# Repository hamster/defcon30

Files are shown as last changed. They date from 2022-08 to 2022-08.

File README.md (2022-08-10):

# defcon 30 SAOs

Hello!  I'm [@hamster](https://twitter.com/hamster) and I was honored this year to be able to make a couple of SAOs for defcon.  I tried to make these simple and fun, and I hope you enjoy them.

The first one is the [SAO Modem 1.69bis](modem), which is a throwback to the days of the external Courier modem screaming away at the internet.  It does not actually communicate with the internet, but it sure is blinky.

modem

The second one is [SAO Jack](jack), a simple learn to solder kit with the spirit of defcon in the artwork.

jack

I hope you enjoy, and let [me](https://twitter.com/hamster) know what you think!

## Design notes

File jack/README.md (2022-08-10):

# Jack SAO

jack

Jack is a simple SAO soldering kit.  Consisting of 4 LEDs in two colors, two resistors, and a connector, it's an easy way to learn how to solder.

To start, dump your kit out on the table and make sure you have all the parts pictured.  You'll need a soldering iron, solder, and a pair of wire cutters.

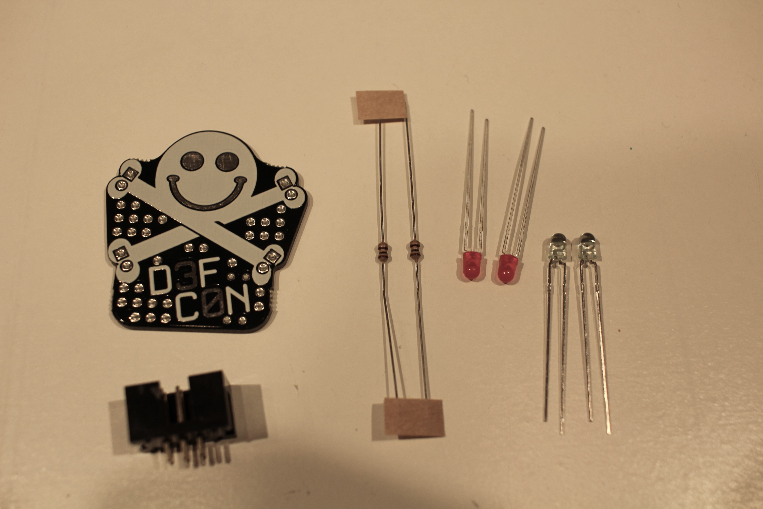
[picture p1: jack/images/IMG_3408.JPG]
parts


Locate the LEDs. Note that typically the LED is cast with a flat spot to indicate the cathode (or negative) terminal.  However, these small LEDS instead have the shorter leg as the cathode.

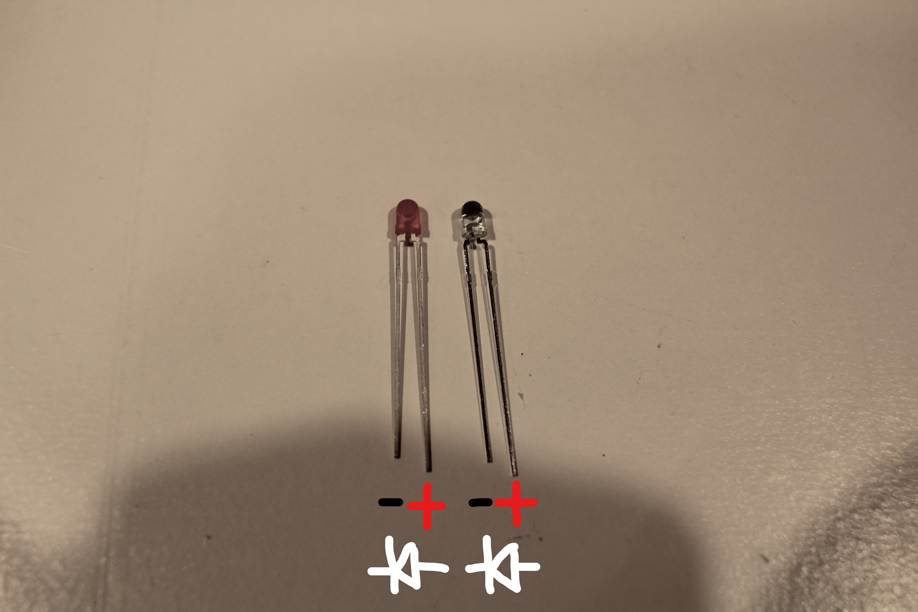
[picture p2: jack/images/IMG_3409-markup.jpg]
cathode


Look at the back of the PCB.  Note the diagram for the LEDS - the short legs of the LEDs will all go towards the top of the PCB.  This is also the square holes on the board.

It doesn't matter which color you put where.  Get crazy with it.  You can even leave the legs a little long and bend the LEDs to point out.  Whatever you want to do.

Insert the LEDs and flip over the PCB.  Make sure the short legs are going through the square holes.  Solder the legs into place.

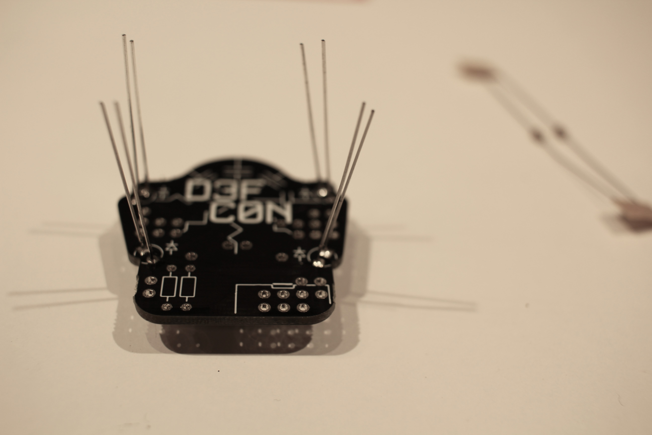
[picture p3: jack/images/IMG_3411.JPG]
legs


Now that the LEDs are in place, you can clip the legs off with your wire cutters.

Locate the two resistors.  Bend their legs down and insert them from the back into the holes above and below the two rectangles on the lower left as shown.

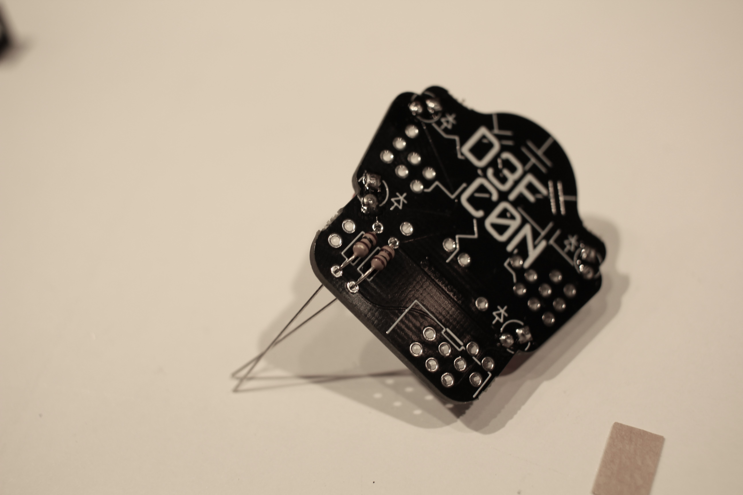
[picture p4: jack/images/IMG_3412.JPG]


Now flip the board over and push the resistors flat.  It helps here to bend the legs out so they can't slip while you are soldering.  Solder the legs down, and clip off the excess legs.

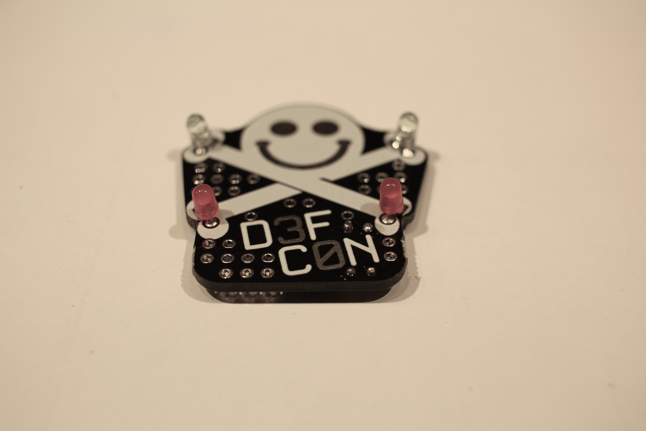
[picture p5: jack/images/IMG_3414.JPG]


Finally, we need to install the SAO connector.  Locate the connector, and note on the back that the notch or tab needs to go 'up'.

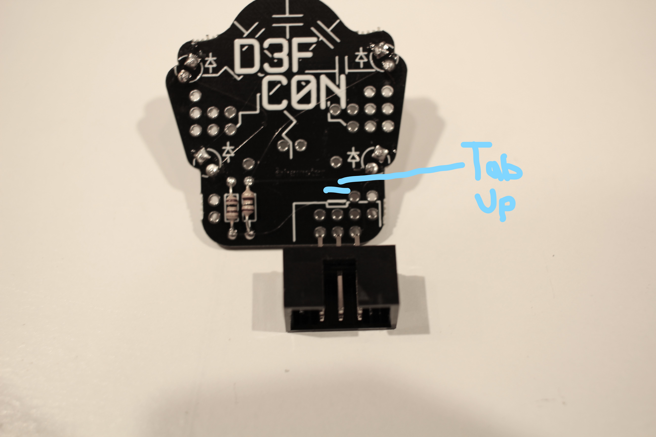
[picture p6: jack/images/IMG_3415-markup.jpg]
SAO


Flip the board over, and solder the connector on.  I like to solder one pin, and then lift the board and pinch the connector while re-applying heat so that the connector is mounted flat, before finishing the solder of the rest of the pins.

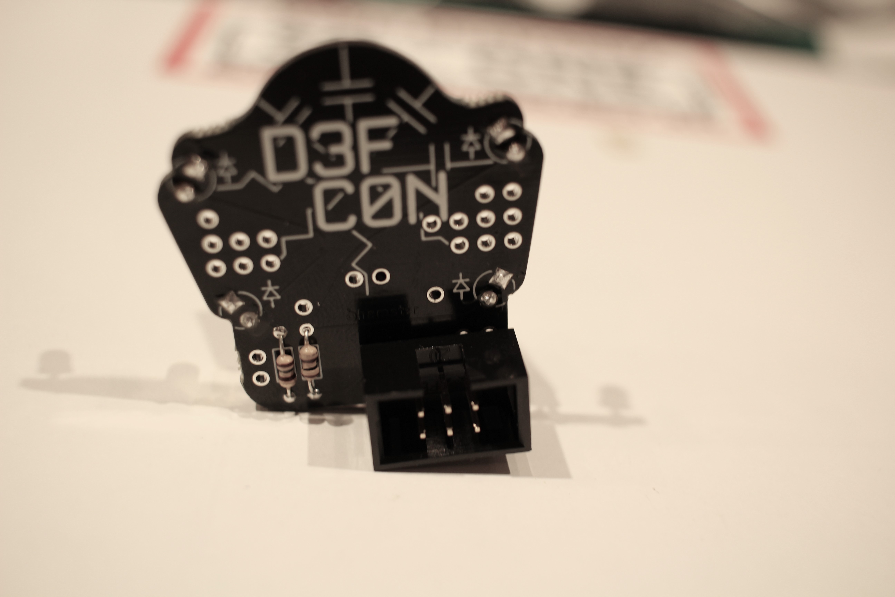
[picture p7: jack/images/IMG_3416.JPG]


You're all done!  Enjoy your SAO and let [me](https://twitter.com/hamster) know what you think!

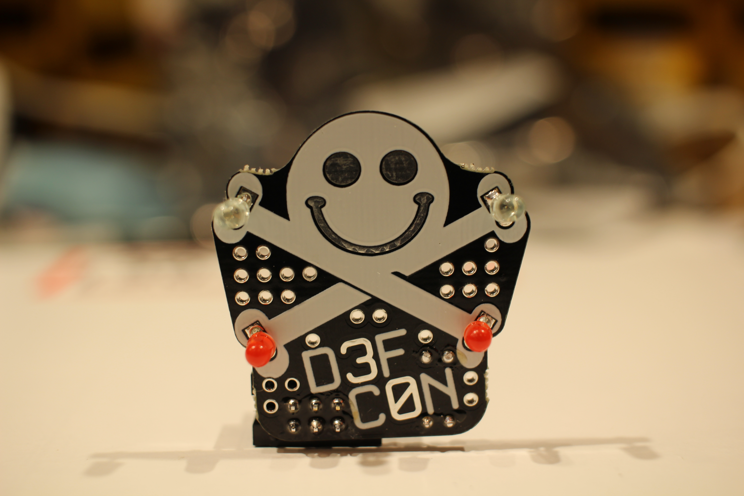
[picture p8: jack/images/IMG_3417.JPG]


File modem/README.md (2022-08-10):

# SAO Modem 1.69bis

SAO

This SAO is designed to add some blinky lights to your badge, calling back to the days of an external Courier modem screaming away on the internet.

There are 6 lights:

- AA - Power, lights when 3.3v is present
- OH - Flashes on I2C SCL activity
- SD - Flashes on I2C SDA activity
- RTS - Flashes on GPIO1 activity
- CTS - Flashes on GPIO2 activity
- SYN - Connected to a free pad on the back, you choose what it does

The I2C inputs were selected to minimize load on the I2C bus, but this SAO might cause issues with badges with high speed I2C.  In that case, you can swap R7 and R8 for higher value resistors.

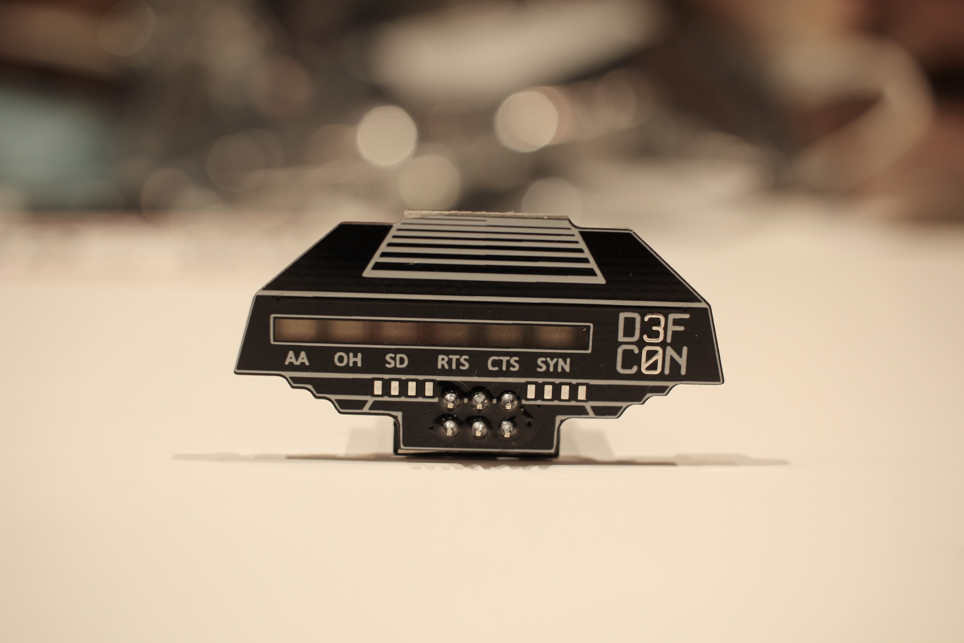
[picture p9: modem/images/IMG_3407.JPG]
SAO


You will need to solder on the SAO connector.  Note that the notch or tab goes towards the top.  See photo for reference.  I like to insert the connector, solder one pin, then pinch the connector to the board with my fingers and re-heat this connection so that the connector snaps flat to the board before I solder on the rest of the pins.

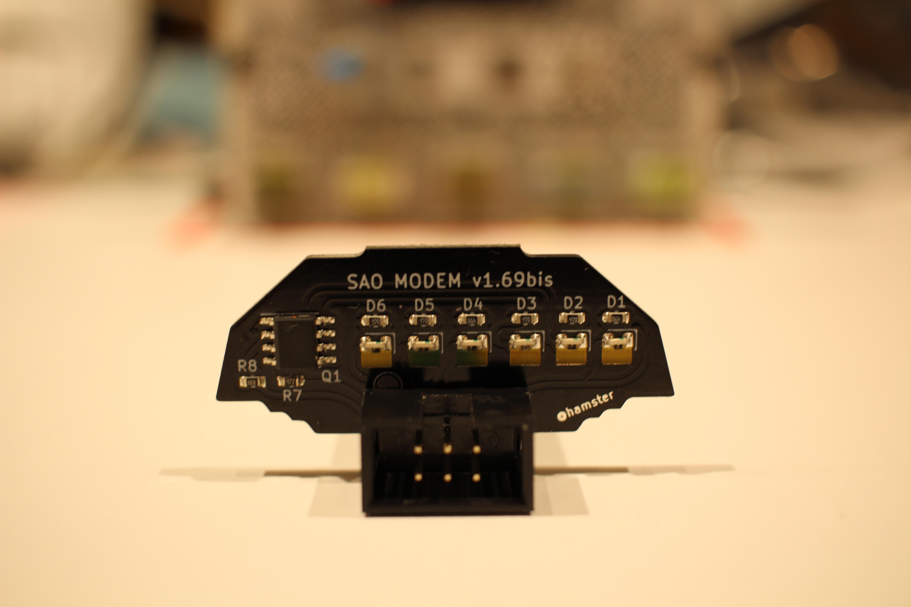
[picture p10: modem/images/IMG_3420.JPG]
connector


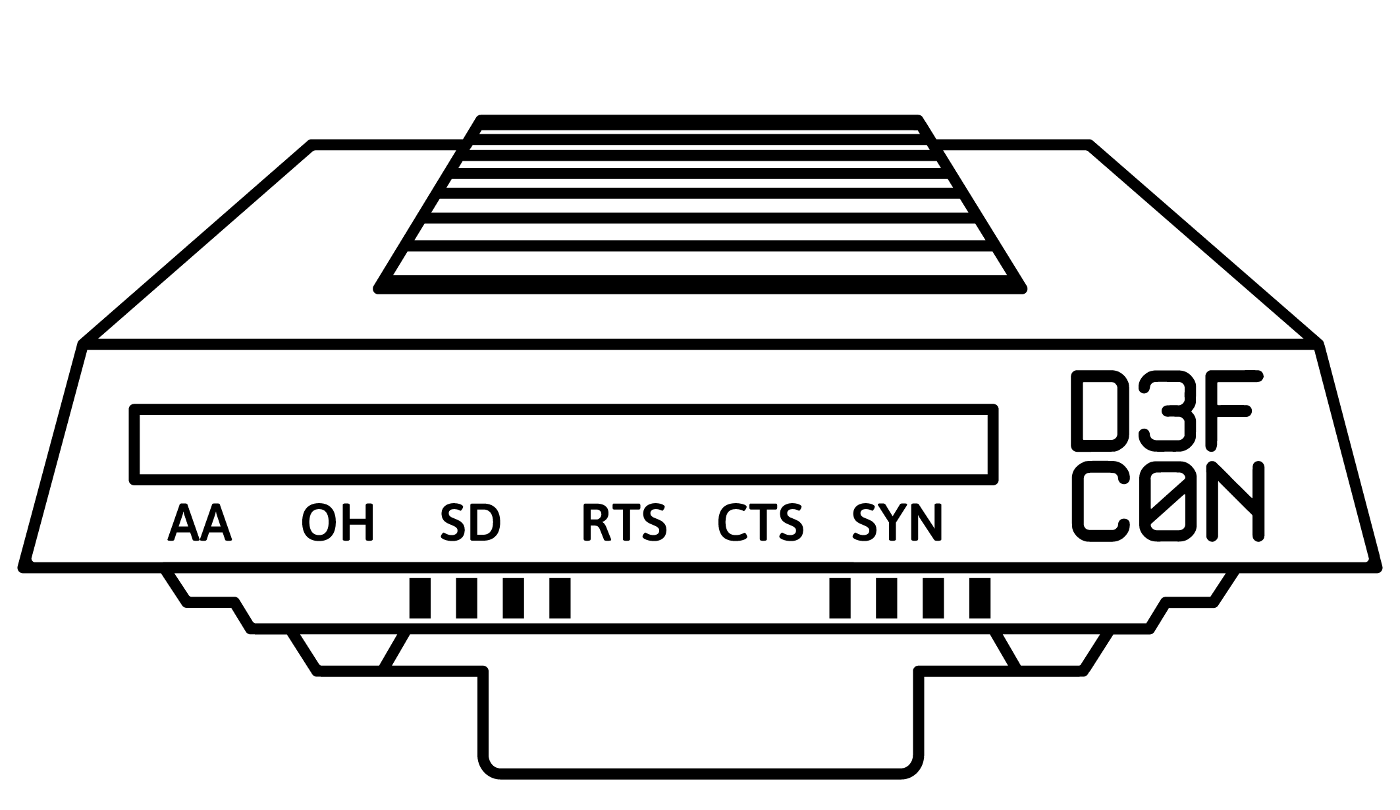
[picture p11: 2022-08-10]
modem/images/modem_Modem.png

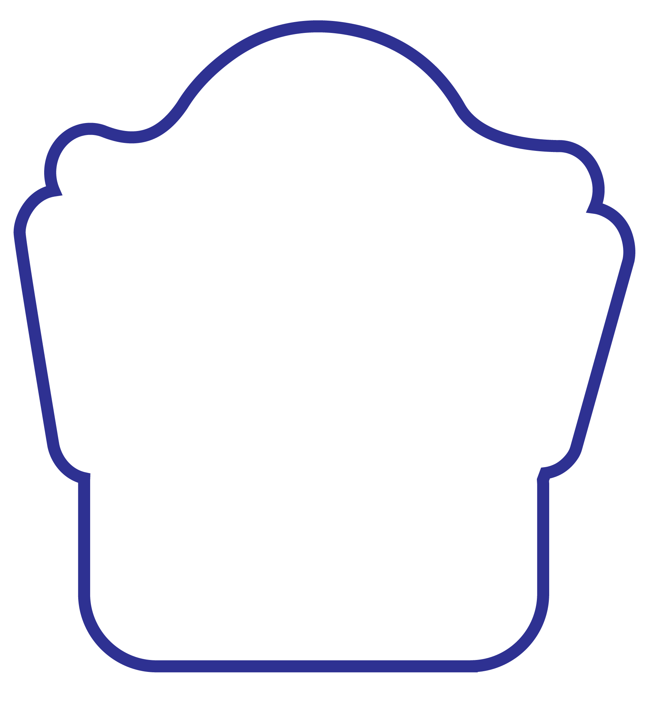
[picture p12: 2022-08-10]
jack/images/jack_Outline.png

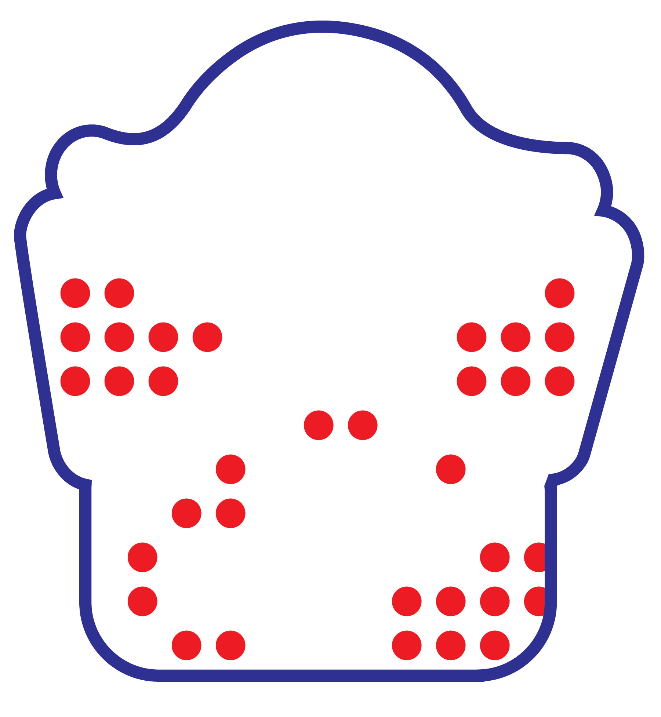
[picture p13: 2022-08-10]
jack/images/jack_Back.png

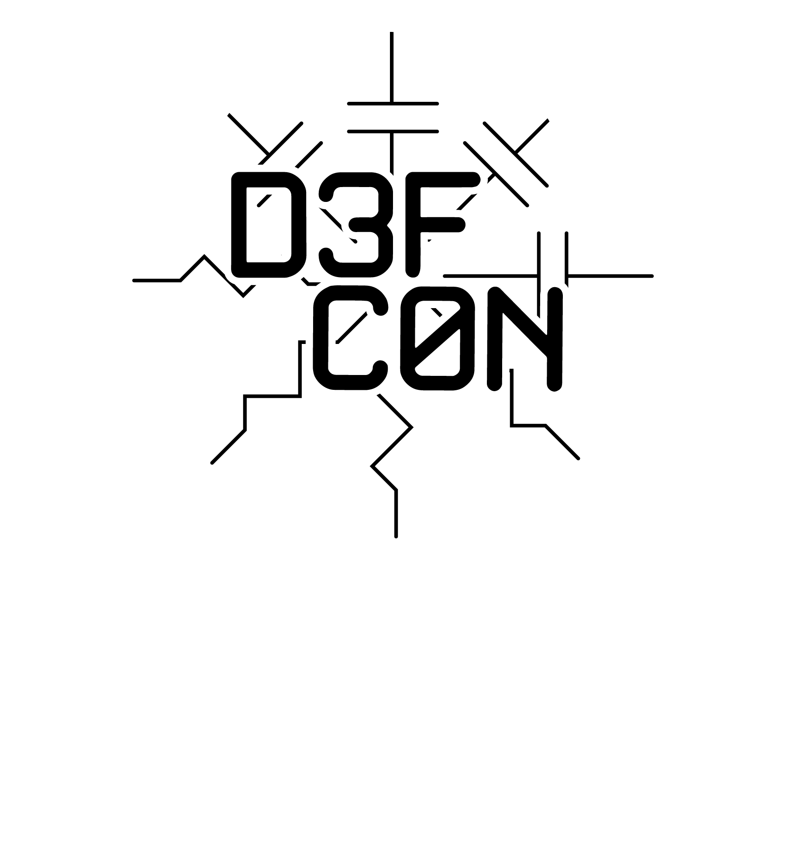
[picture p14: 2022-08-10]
jack/images/jack-06.png

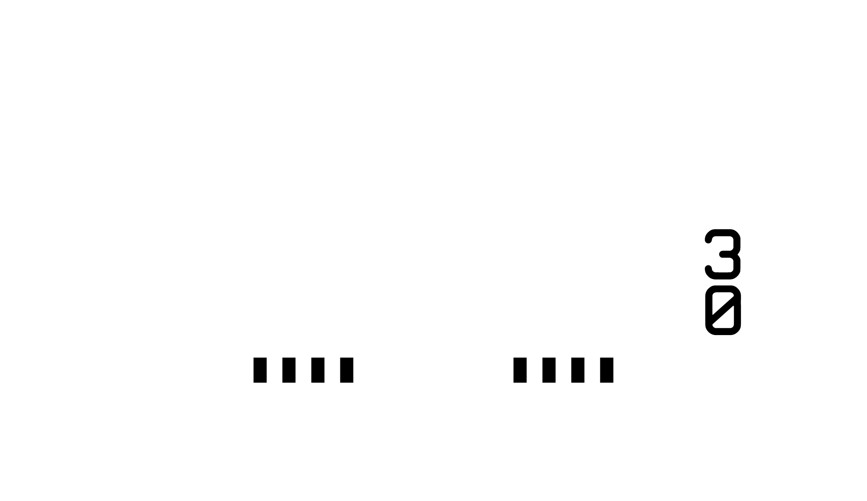
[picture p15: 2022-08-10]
modem/images/modem_Copper.png

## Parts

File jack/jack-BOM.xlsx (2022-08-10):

RefDes | Description | Part | Supplier Link | Qty/Badge
D1,D3 | Green T1 LED | HLMP1540 | https://www.digikey.com/en/products/detail/everlight-electronics-co-ltd/HLMP1540/2675537 | 2
D2,D4 | Red T1 LED | LTL-4211N | https://www.digikey.com/en/products/detail/liteon/LTL-4211N/3198521 | 2
R1,R2 | 100 ohm 1/8W resistor | CF18JT100R | https://www.digikey.com/en/products/detail/stackpole-electronics-inc/CF18JT100R/1741562 | 2
X1 | SAO connector, shrouded | 61200621621 | https://www.mouser.com/ProductDetail/710-61200621621 | 1

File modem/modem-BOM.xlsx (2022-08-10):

RefDes | Description | Part | Supplier Link | Supplier Part | Qty/Badge
D1-6 | Red LED RA 0805 | LTST-S220KRKT | https://www.digikey.com/en/products/detail/LTST-S220KRKT/160-1469-1-ND/386876 | 160-1469-2-ND | 6
R1-6 | 47R 0603 | RMCF0603FT47R0 | https://www.digikey.com/en/products/detail/stackpole-electronics-inc/RMCF0603FT47R0/1761141 | RMCF0603FT47R0TR-ND | 6
R7 | 4.7k 0603 | RMCF0603JT4K70 | https://www.digikey.com/en/products/detail/stackpole-electronics-inc/RMCF0603JT4K70/1757976 | RMCF0603JT4K70TR-ND | 1
R8 | 10k 0603 | RMCF0603JT10K0 | https://www.digikey.com/en/products/detail/stackpole-electronics-inc/RMCF0603JT10K0/1758104 | RMCF0603JT10K0TR-ND | 1
Q1 | Dual P-chan mosfet SOIC-8 | DMP3085LSD-13 | https://www.digikey.com/en/products/detail/diodes-incorporated/DMP3085LSD-13/4251562 | DMP3085LSD-13DITR-ND | 1
X1 | SAO connector, shrouded | 61200621621 | https://www.digikey.com/en/products/detail/61200621621/732-5394-ND/4846913 | 732-5394-ND | 1

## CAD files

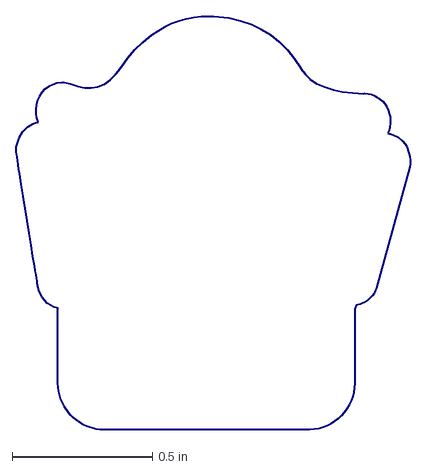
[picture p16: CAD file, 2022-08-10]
jack/images/jack-outline.dxf
1.40 x 1.47 in

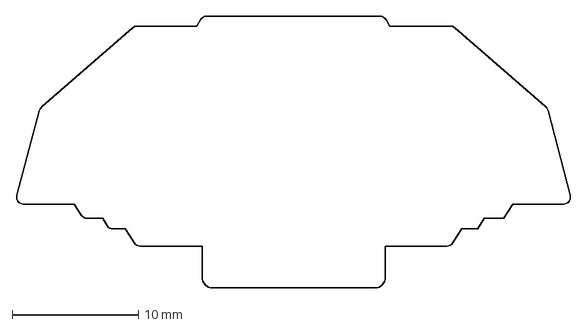
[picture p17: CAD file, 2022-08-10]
modem/images/modem.dxf
43.9 x 21.5 mm

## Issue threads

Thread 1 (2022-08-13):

Screen doesn’t turn on on DC30 badge after installing Modem SAO

abjugard, 2022-08-13:
The screen doesn’t turn on on DC30 badge after installing the Modem SAO. What is the solution that can be applied at the con?

hamster, 2022-08-13:
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
The SAO loads the i2c bus too much. It's not being used for the SAO other than to flash activity. You can replace R7 and R8 with higher value resistors or cut the i2c lines as indicated on the badge (see photo).

hamster, 2022-08-13:
R7 and R8 are on the modem SAO.

Closed 2022-08-13.

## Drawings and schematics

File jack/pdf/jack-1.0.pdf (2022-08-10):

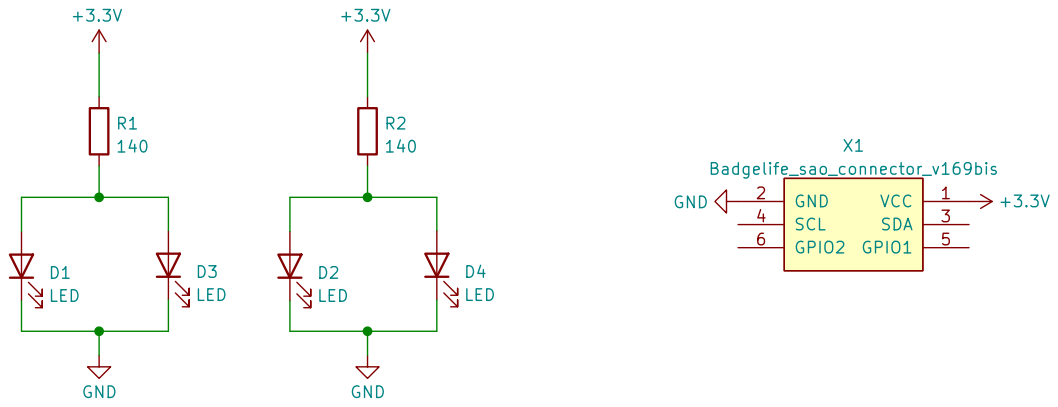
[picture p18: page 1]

github.com/hamster/defcon30 GND

File: jack.kicad_sch Sheet: / @hamster

Id: 1/1 Title: SAO Jack

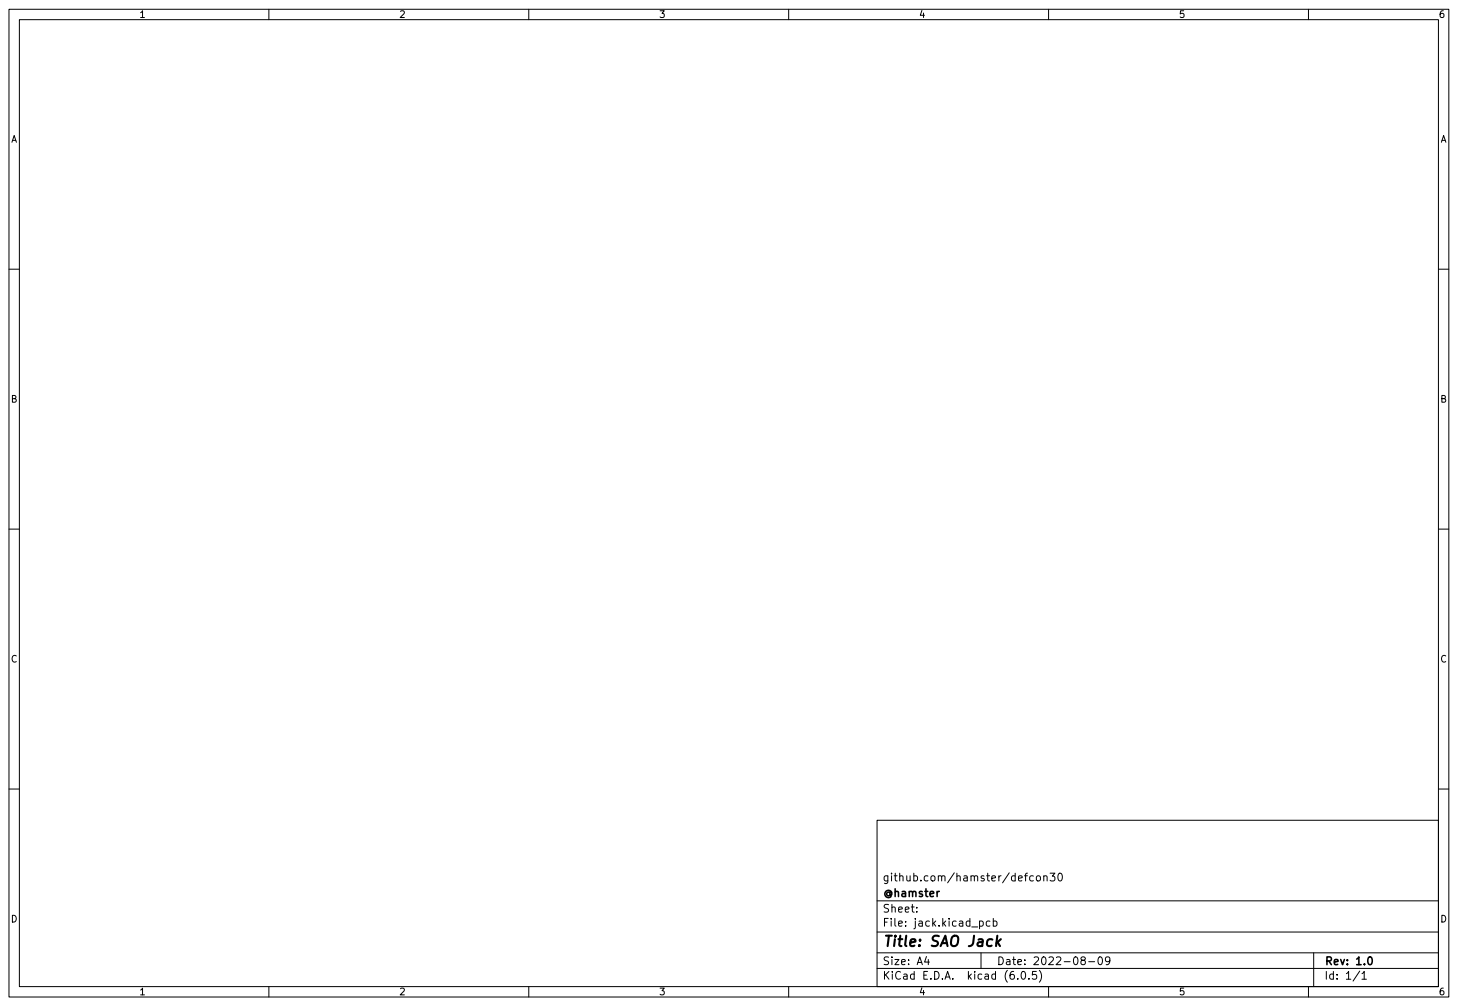
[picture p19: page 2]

github.com/hamster/defcon30
File: jack.kicad_pcb Sheet: @hamster

Id: 1/1 Title: SAO Jack

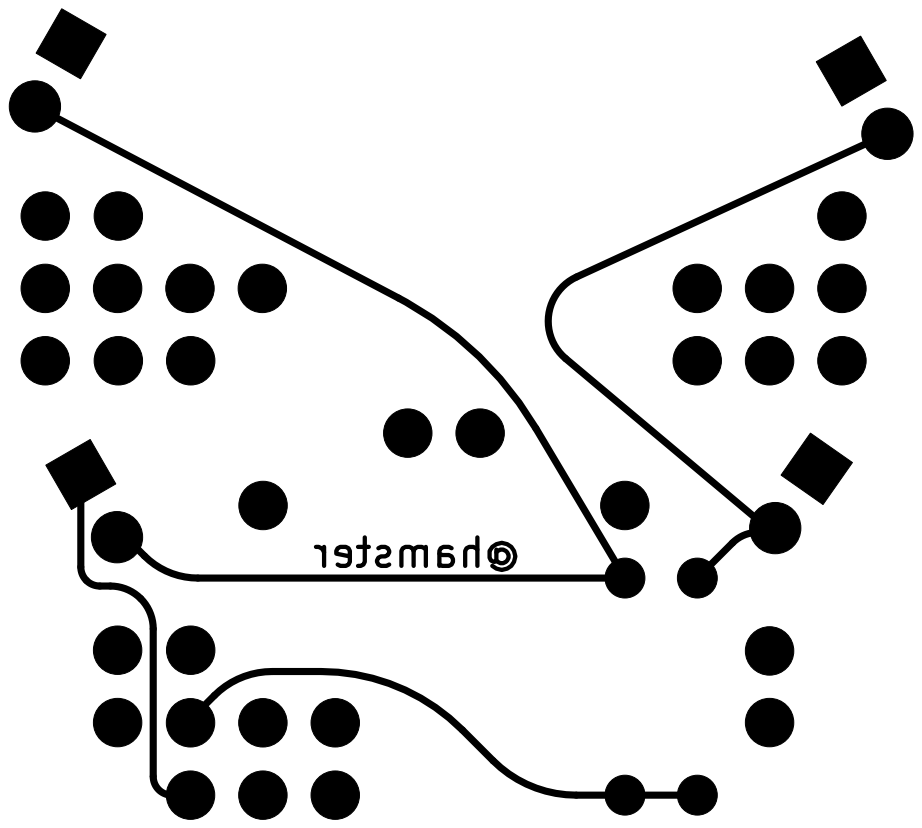
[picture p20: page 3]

github.com/hamster/defcon30 @hamster

File: jack.kicad_pcb Sheet: @hamster

Id: 1/1 Title: SAO Jack

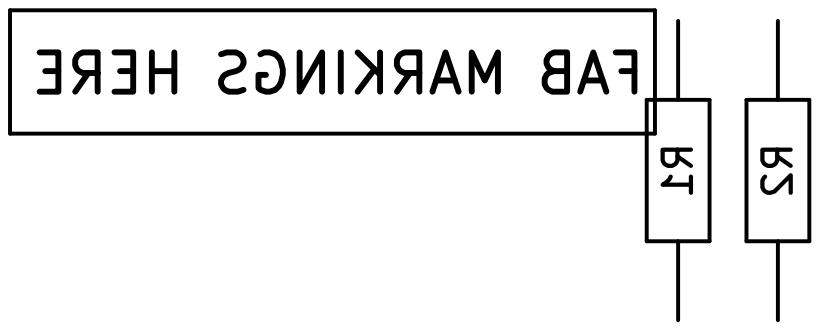
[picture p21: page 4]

github.com/hamster/defcon30
File: jack.kicad_pcb Sheet: @hamster

Id: 1/1 Title: SAO Jack

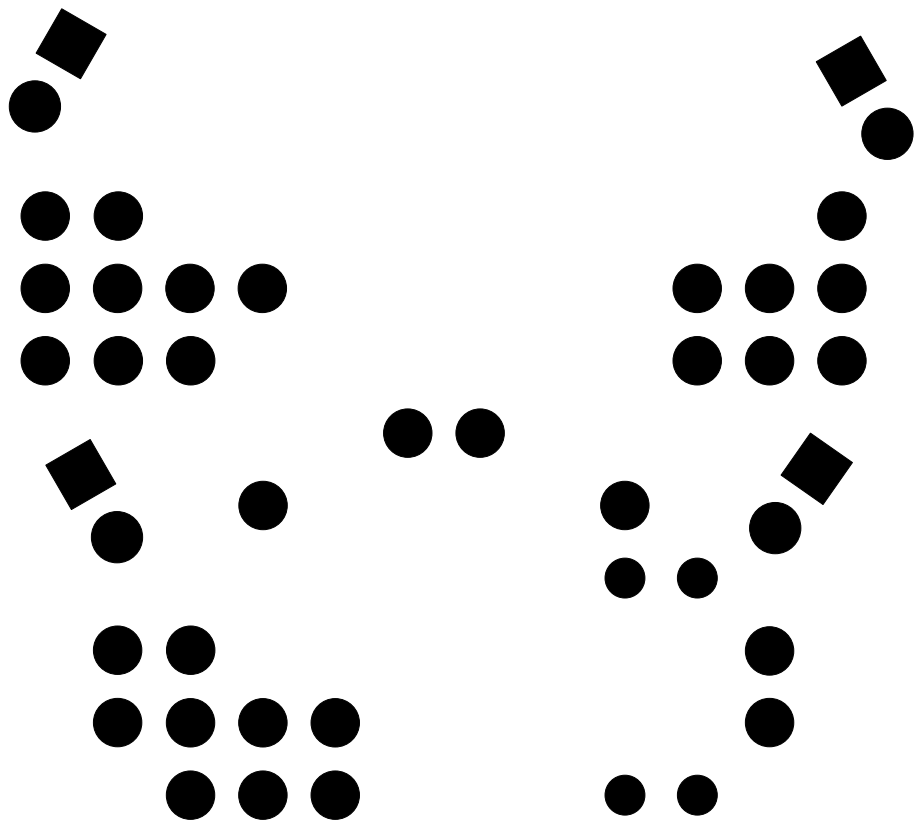
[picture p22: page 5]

github.com/hamster/defcon30
File: jack.kicad_pcb Sheet: @hamster

Id: 1/1 Title: SAO Jack

github.com/hamster/defcon30
File: jack.kicad_pcb Sheet: @hamster

Id: 1/1 Title: SAO Jack

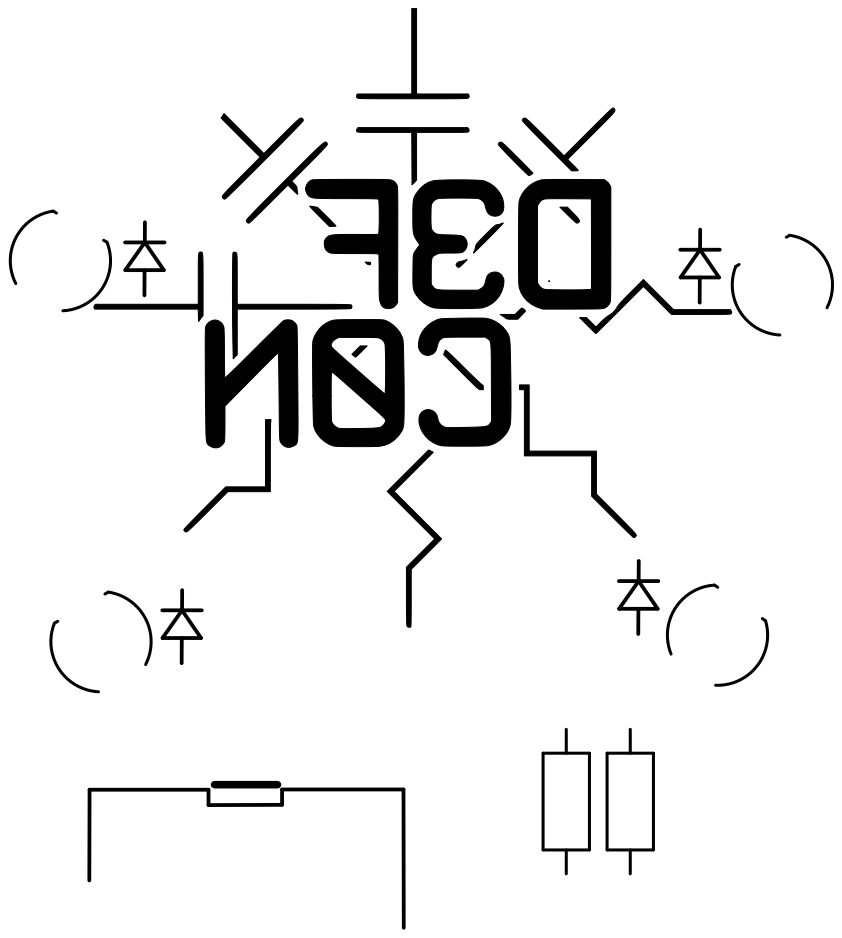
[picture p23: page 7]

github.com/hamster/defcon30
File: jack.kicad_pcb Sheet: @hamster

Id: 1/1 Title: SAO Jack

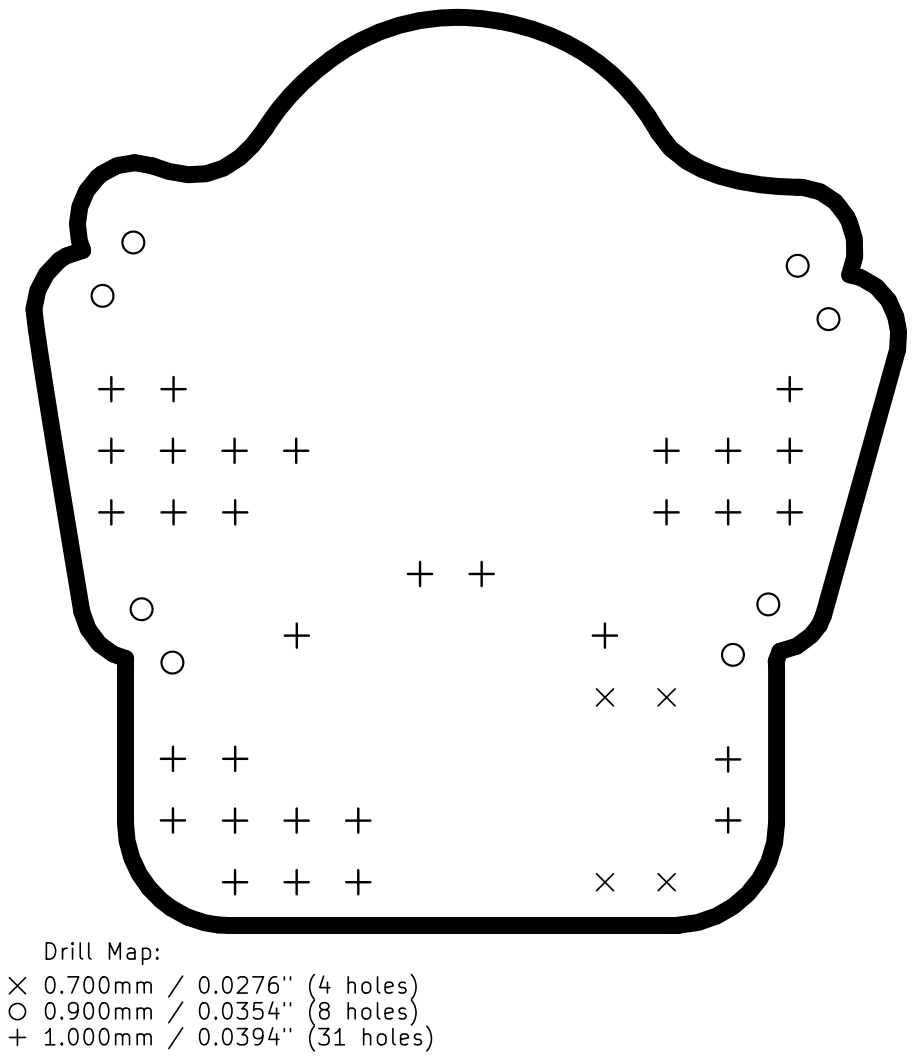
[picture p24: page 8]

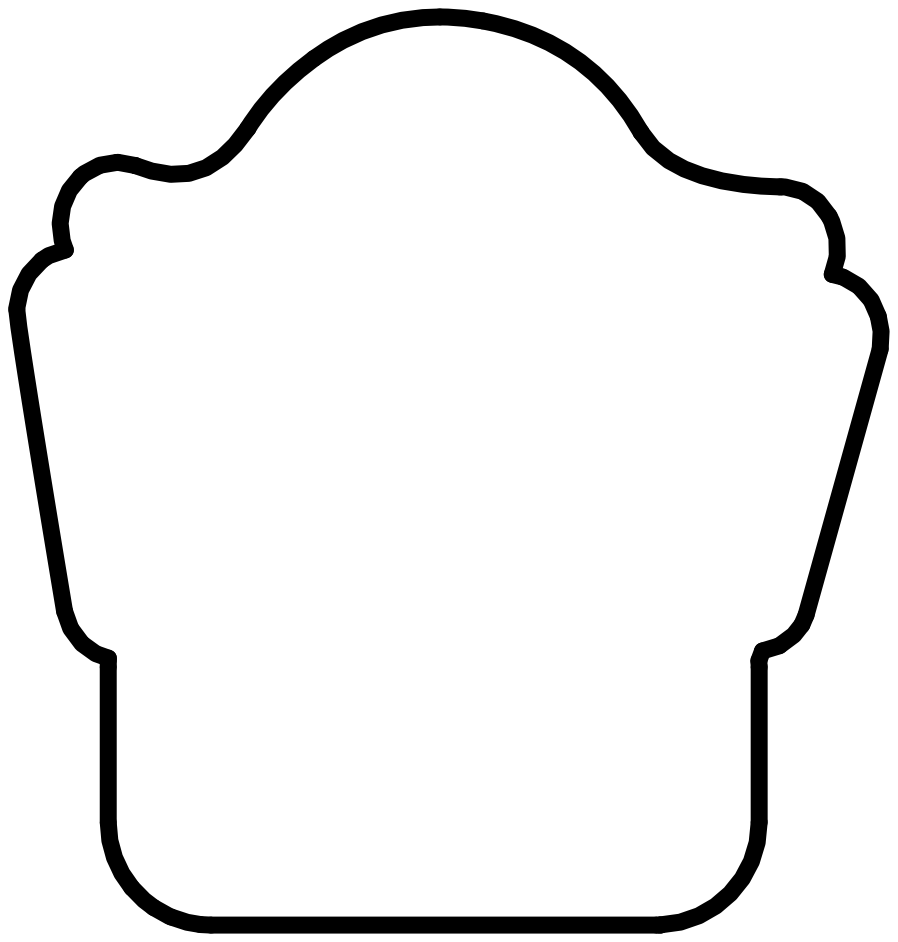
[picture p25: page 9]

github.com/hamster/defcon30
File: jack.kicad_pcb Sheet: @hamster

Id: 1/1 Title: SAO Jack

github.com/hamster/defcon30
File: jack.kicad_pcb Sheet: @hamster

Id: 1/1 Title: SAO Jack

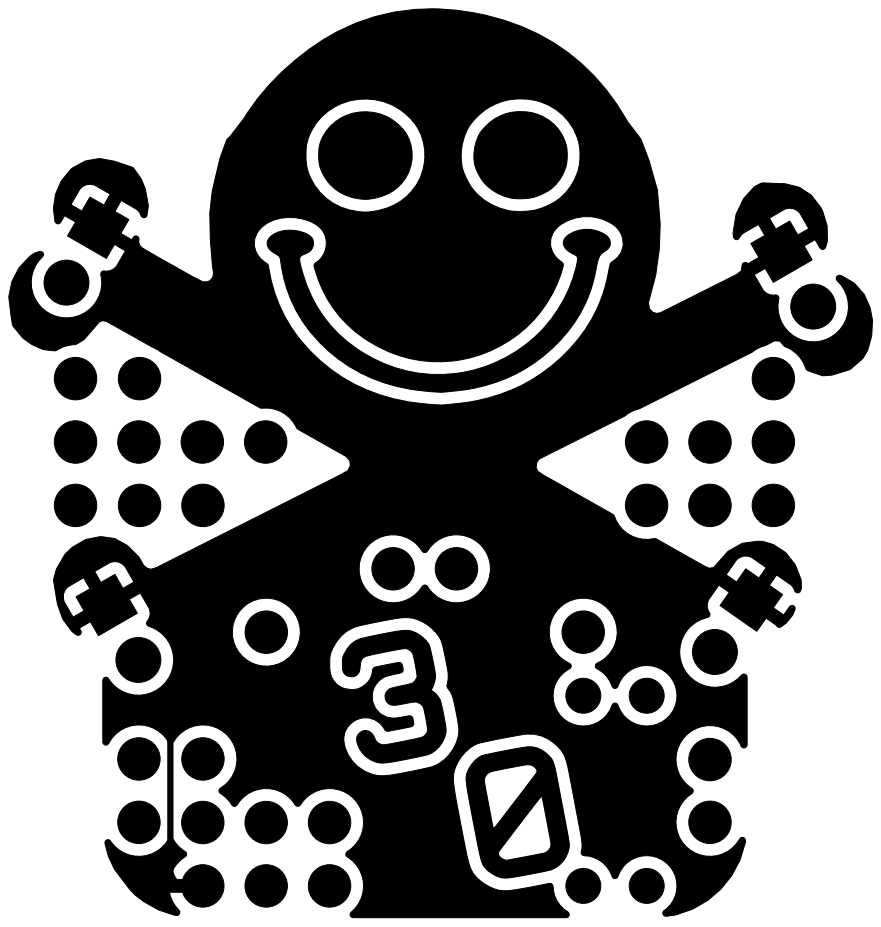
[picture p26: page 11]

github.com/hamster/defcon30
File: jack.kicad_pcb Sheet: @hamster

Id: 1/1 Title: SAO Jack

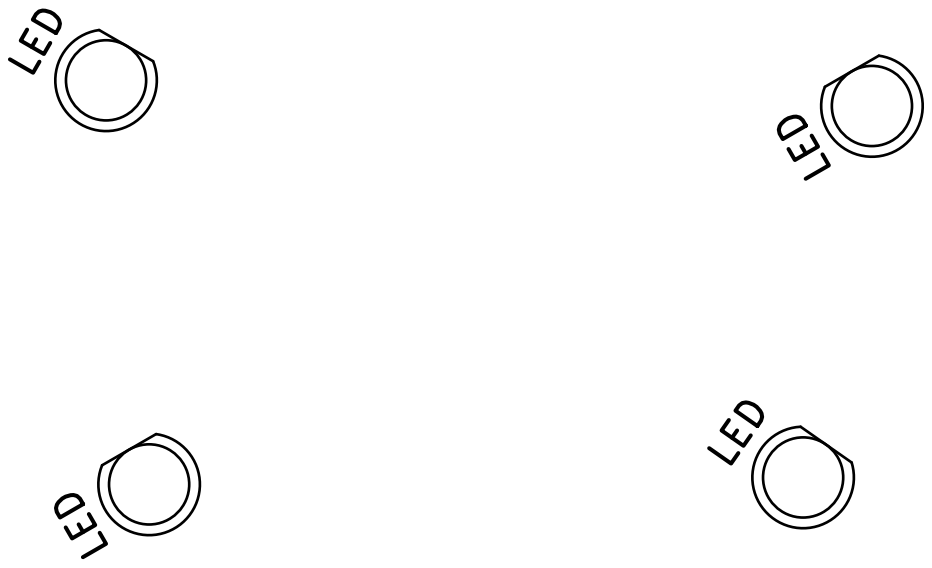
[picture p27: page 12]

github.com/hamster/defcon30
File: jack.kicad_pcb Sheet: @hamster

Id: 1/1 Title: SAO Jack

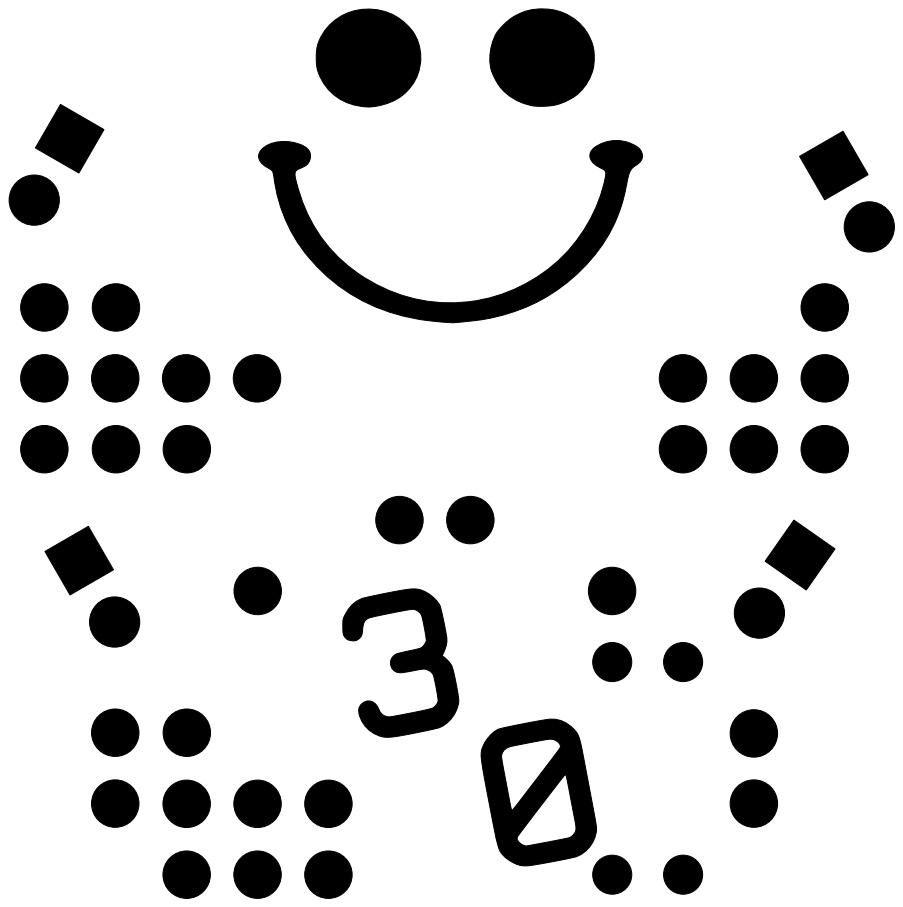
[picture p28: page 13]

github.com/hamster/defcon30
File: jack.kicad_pcb Sheet: @hamster

Id: 1/1 Title: SAO Jack

github.com/hamster/defcon30
File: jack.kicad_pcb Sheet: @hamster

Id: 1/1 Title: SAO Jack

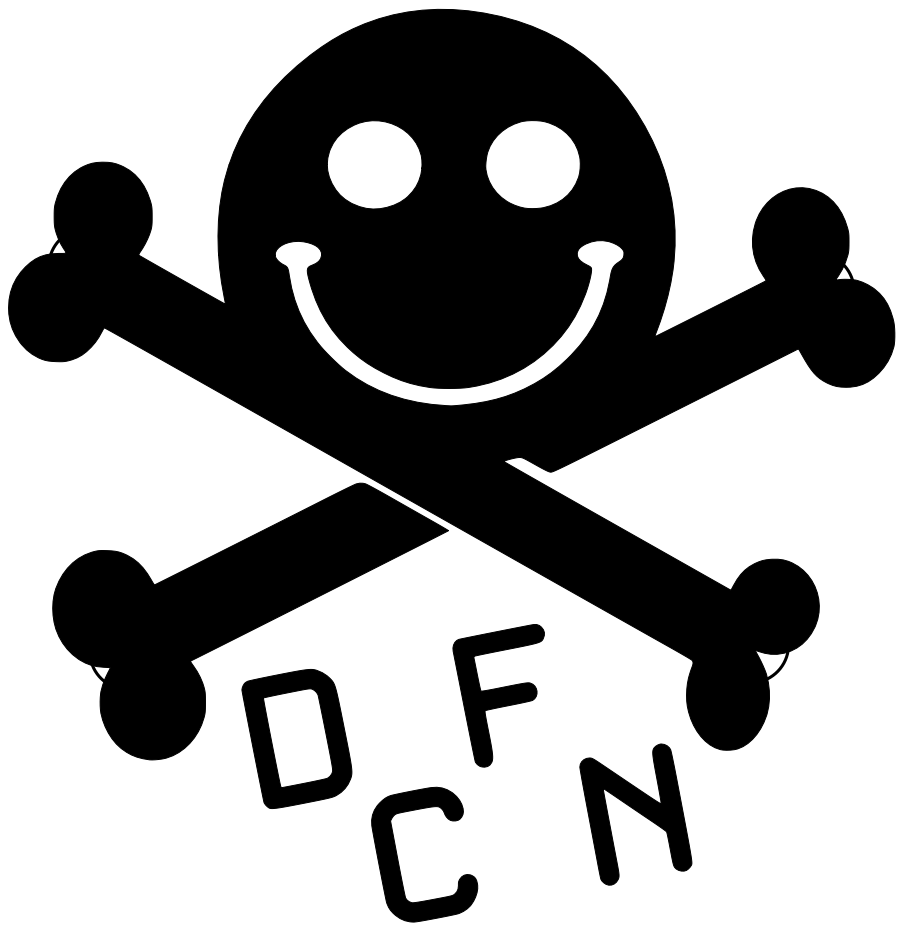
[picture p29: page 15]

github.com/hamster/defcon30
File: jack.kicad_pcb Sheet: @hamster

Id: 1/1 Title: SAO Jack

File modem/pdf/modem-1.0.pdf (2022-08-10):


File: modem.kicad_sch Sheet: / hamster github.com/hamster/defcon30 GND

Id: 1/1 Title: SAO Modem v1.69bis


github.com/hamster/defcon30
File: modem.kicad_pcb Sheet: @hamster

Id: 1/1 Title: SAO Modem v1.69bis


github.com/hamster/defcon30
File: modem.kicad_pcb Sheet: @hamster

Id: 1/1 Title: SAO Modem v1.69bis


github.com/hamster/defcon30
File: modem.kicad_pcb Sheet: @hamster

Id: 1/1 Title: SAO Modem v1.69bis


github.com/hamster/defcon30
File: modem.kicad_pcb Sheet: @hamster

Id: 1/1 Title: SAO Modem v1.69bis



github.com/hamster/defcon30
File: modem.kicad_pcb Sheet: @hamster

Id: 1/1 Title: SAO Modem v1.69bis


github.com/hamster/defcon30
File: modem.kicad_pcb Sheet: @hamster

Id: 1/1 Title: SAO Modem v1.69bis


github.com/hamster/defcon30
File: modem.kicad_pcb Sheet: @hamster

Id: 1/1 Title: SAO Modem v1.69bis


github.com/hamster/defcon30
File: modem.kicad_pcb Sheet: @hamster

Id: 1/1 Title: SAO Modem v1.69bis

github.com/hamster/defcon30
File: modem.kicad_pcb Sheet: @hamster

Id: 1/1 Title: SAO Modem v1.69bis


github.com/hamster/defcon30
File: modem.kicad_pcb Sheet: @hamster

Id: 1/1 Title: SAO Modem v1.69bis

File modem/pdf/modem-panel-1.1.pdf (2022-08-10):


github.com/hamster/defcon30
D Date: 2022-07-14 KiCad E.D.A. kicad (6.0.5)
File: modem-panel.kicad_pcb Sheet: @hamster

Id: 1/1 Title: SAO Modem v1.69bis Panel

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

Id: 1/1 Title: SAO Modem v1.69bis Panel

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

Id: 1/1 Title: SAO Modem v1.69bis Panel

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

Id: 1/1 Title: SAO Modem v1.69bis Panel


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

Id: 1/1 Title: SAO Modem v1.69bis Panel

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

Id: 1/1 Title: SAO Modem v1.69bis Panel

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

Id: 1/1 Title: SAO Modem v1.69bis Panel

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

Id: 1/1 Title: SAO Modem v1.69bis Panel

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

Id: 1/1 Title: SAO Modem v1.69bis Panel

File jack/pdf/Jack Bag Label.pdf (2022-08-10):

# JACK


Instructions at
https://github.com/hamster/defcon30/jack

Flat is Cathode

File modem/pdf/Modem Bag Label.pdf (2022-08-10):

# MODEM


Instructions at
https://github.com/hamster/defcon30/modem

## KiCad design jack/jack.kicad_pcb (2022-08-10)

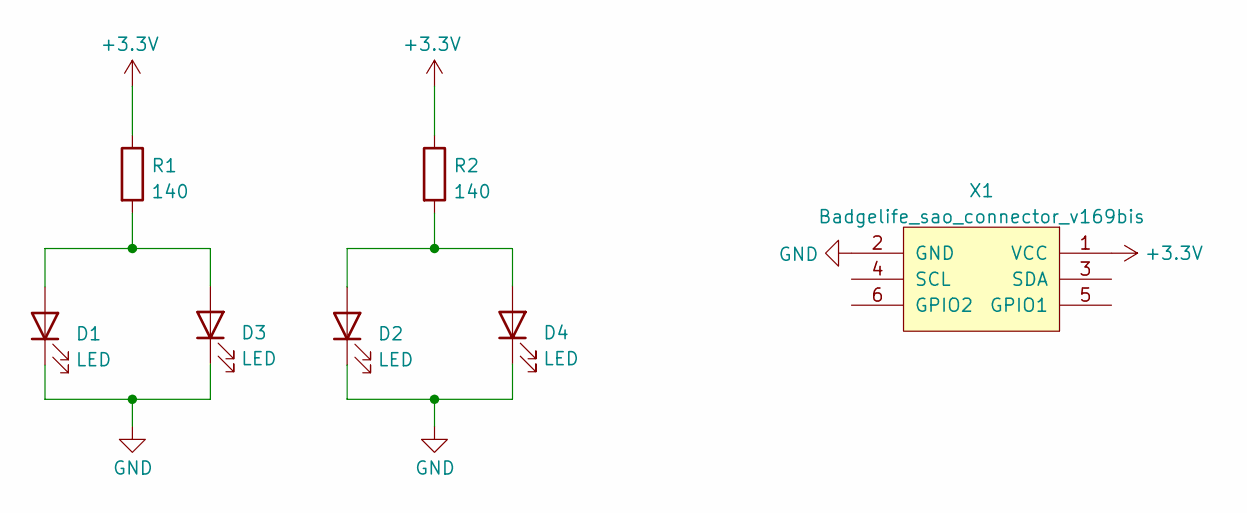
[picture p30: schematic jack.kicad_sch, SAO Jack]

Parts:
D1, D2, D3, D4: LED; LED_D3.0mm
R1, R2: 140; R_Axial_DIN0204_L3.6mm_D1.6mm_P7.62mm_Horizontal
X1: Badgelife_sao_connector_v169bis; Badgelife-Shitty-v1.69bis

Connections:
+3V3: R1.1, R2.1, X1.1 (VCC)
GND: D1.1 (K), D2.1 (K), D3.1 (K), D4.1 (K), X1.2 (GND)
unnamed: D1.2 (A), D3.2 (A), R1.2
unnamed: D2.2 (A), D4.2 (A), R2.2

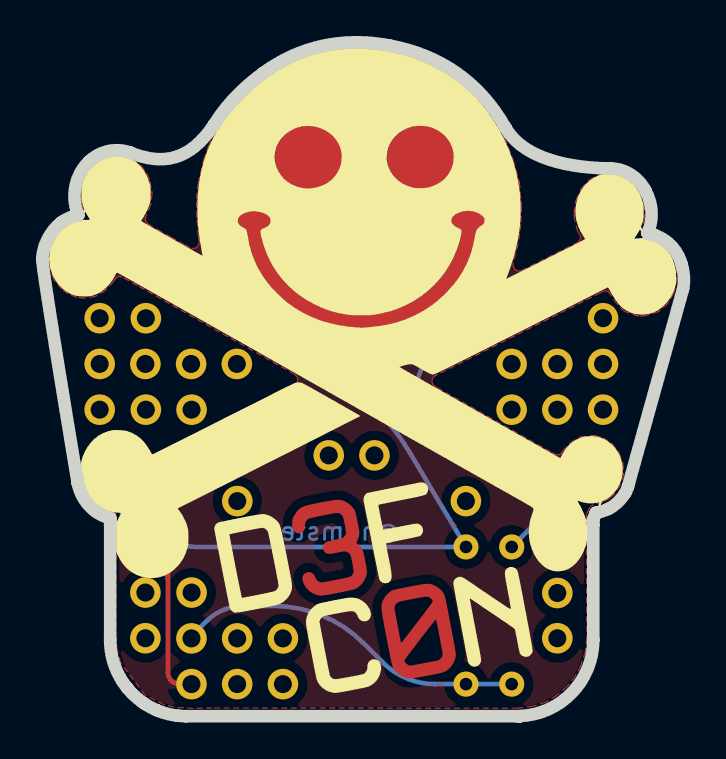
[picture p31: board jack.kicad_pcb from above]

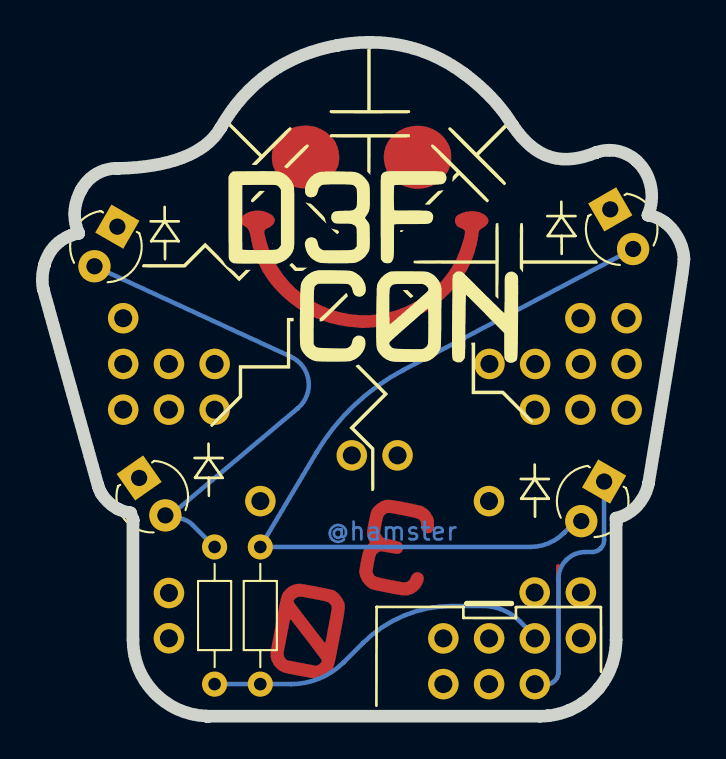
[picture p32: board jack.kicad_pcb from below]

Board: 2 copper layers, 35.6 x 37.4 mm, 7 parts (2 on the bottom side), 4 nets.

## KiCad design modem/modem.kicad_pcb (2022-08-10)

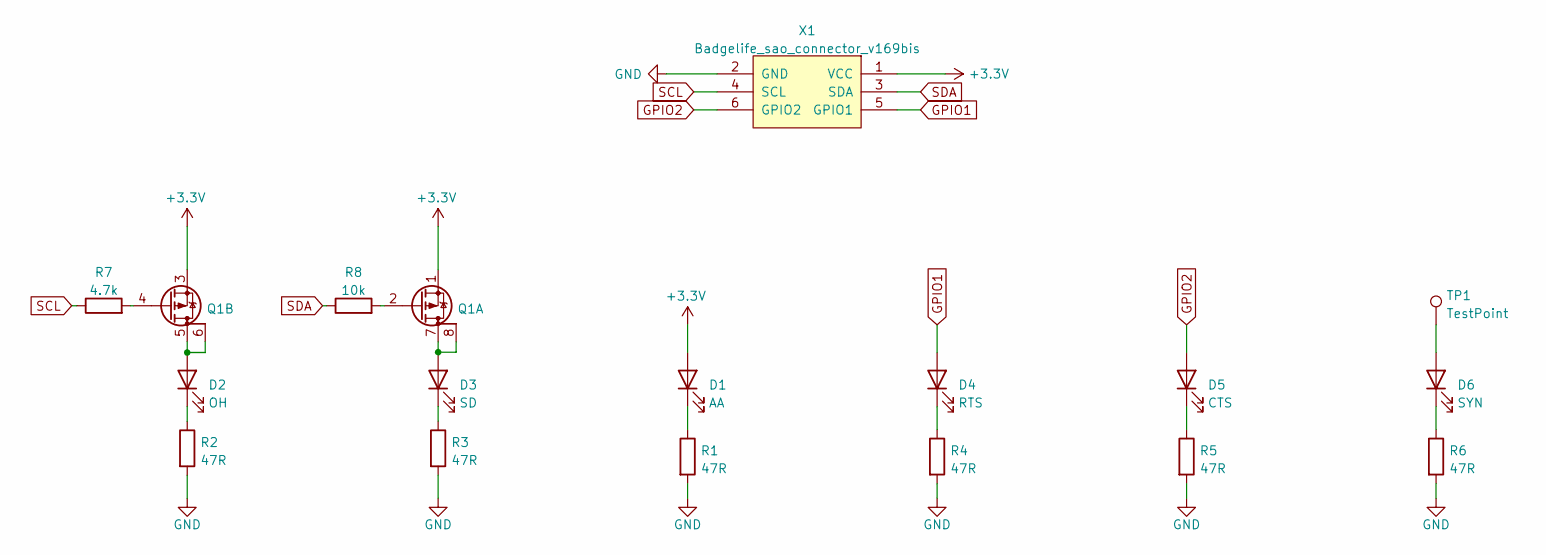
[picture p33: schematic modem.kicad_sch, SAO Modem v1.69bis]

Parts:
D1: AA; LED_0805_2012Metric
D2: OH; LED_0805_2012Metric
D3: SD; LED_0805_2012Metric
D4: RTS; LED_0805_2012Metric
D5: CTS; LED_0805_2012Metric
D6: SYN; LED_0805_2012Metric
Q1: Q_Dual_PMOS_S1G1D2S2G2D1; SOIC-8_3.9x4.9mm_P1.27mm
R1, R2, R3, R4, R5, R6: 47R; R_0603_1608Metric
R7: 4.7k; R_0603_1608Metric
R8: 10k; R_0603_1608Metric
TP1: TestPoint; TestPoint_Pad_D2.0mm
X1: Badgelife_sao_connector_v169bis; Badgelife-Shitty-v1.69bis

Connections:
+3V3: D1.2 (A), Q1.1 (S), Q1.3 (S), X1.1 (VCC)
GND: R1.2, R2.2, R3.2, R4.2, R5.2, R6.2, X1.2 (GND)
GPIO1: D4.2 (A), X1.5 (GPIO1)
GPIO2: D5.2 (A), X1.6 (GPIO2)
unnamed: D1.1 (K), R1.1
unnamed: D2.1 (K), R2.1
unnamed: D2.2 (A), Q1.5 (D), Q1.6 (G)
unnamed: D3.1 (K), R3.1
unnamed: D3.2 (A), Q1.7 (D), Q1.8 (G)
unnamed: D4.1 (K), R4.1
unnamed: D5.1 (K), R5.1
unnamed: D6.1 (K), R6.1
unnamed: D6.2 (A), TP1.1
unnamed: Q1.2 (G), R8.2
unnamed: Q1.4 (G), R7.2
SCL: R7.1, X1.4 (SCL)
SDA: R8.1, X1.3 (SDA)

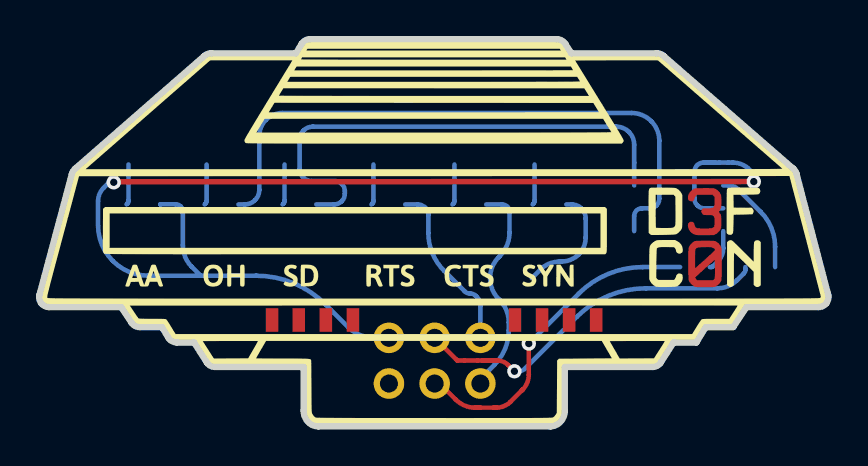
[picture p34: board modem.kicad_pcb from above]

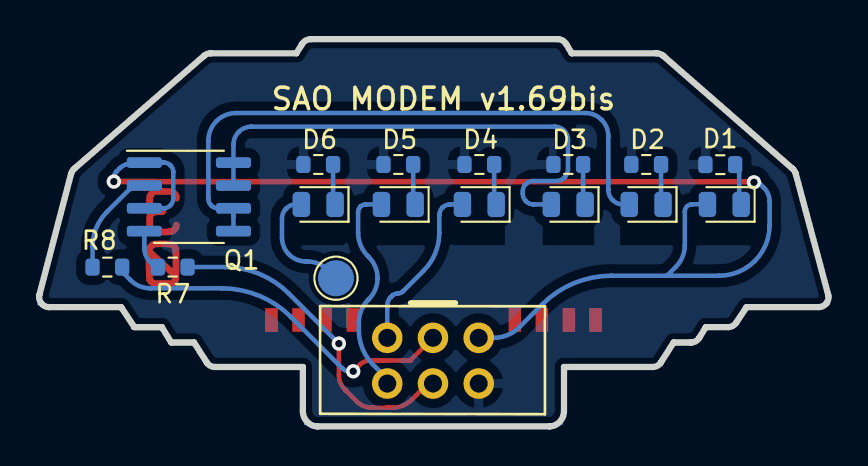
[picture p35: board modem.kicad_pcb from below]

Board: 2 copper layers, 43.9 x 21.5 mm, 19 parts (16 on the bottom side), 17 nets.

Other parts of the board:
tab: Tab
tab#2: Tab
